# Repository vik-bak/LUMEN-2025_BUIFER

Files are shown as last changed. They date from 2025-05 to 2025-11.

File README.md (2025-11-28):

# LUMEN-2025_BUIFER
Development of the hardware and software for smart protection helmet used by construction workers. Three PCBs were design in order to expand the functionalities of the regular protection helmet, code-named after their location on the helmet: BackPCB, FrontPCB and SidePCB. Code written in C, built and loaded into the STM32L476 and ESP Wrover microcontrollers. Implemented local web application developed in React to visualize data from sensors and to notify user about important informations on the construction site. The whole system was tested and proved functional and efficient.

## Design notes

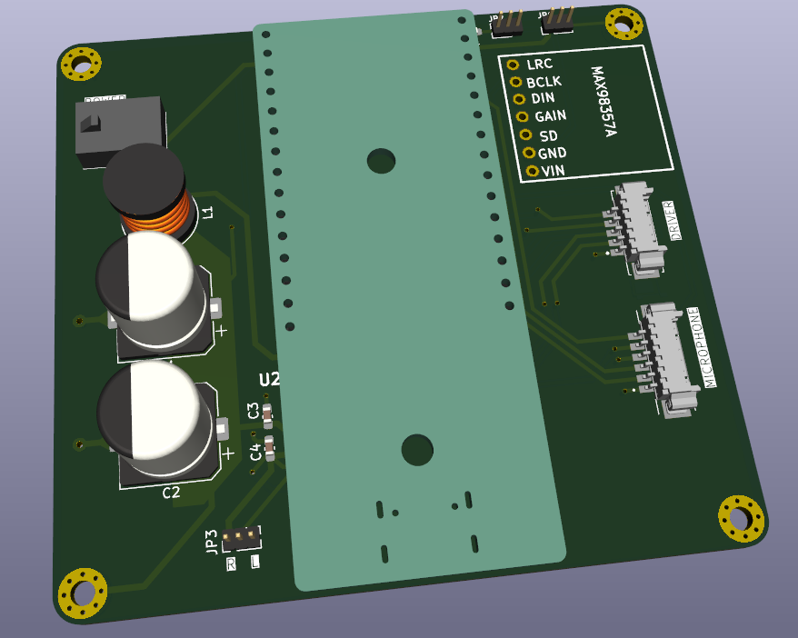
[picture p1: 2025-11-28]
Side_PCB_BUIFER/pcb_side_front.png

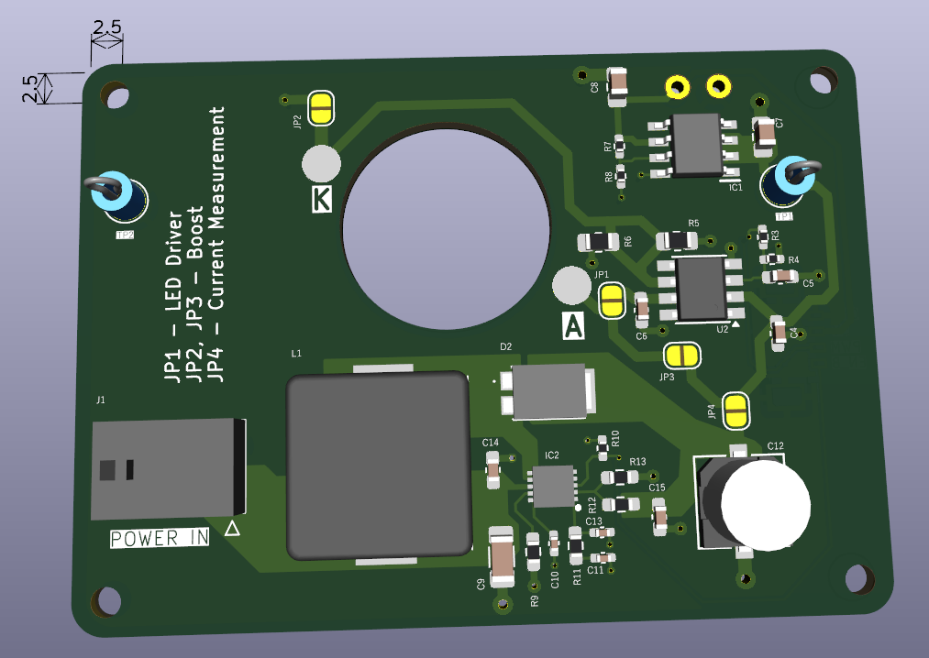
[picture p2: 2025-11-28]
Front_PCB_BUIFER/pcb_front_front.png

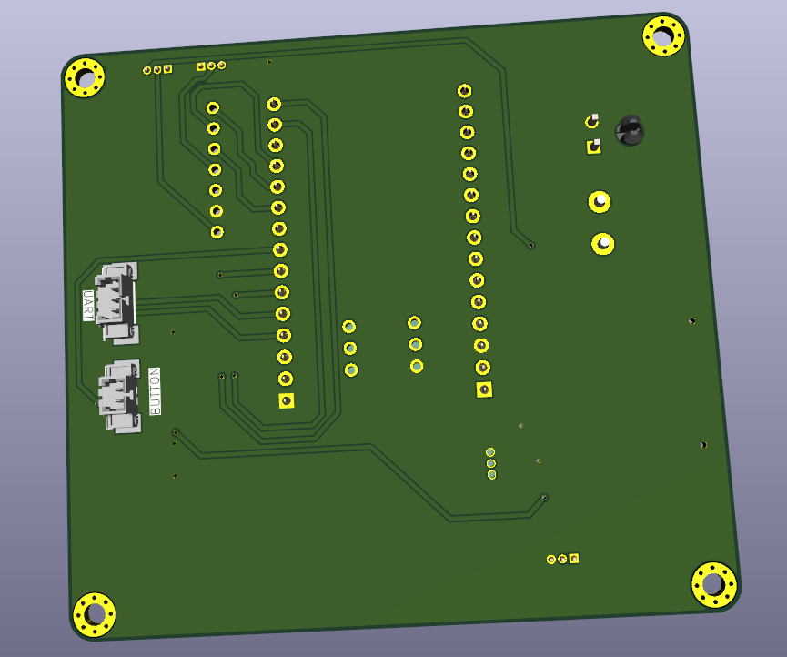
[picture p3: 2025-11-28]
Side_PCB_BUIFER/pcb_side_back.png

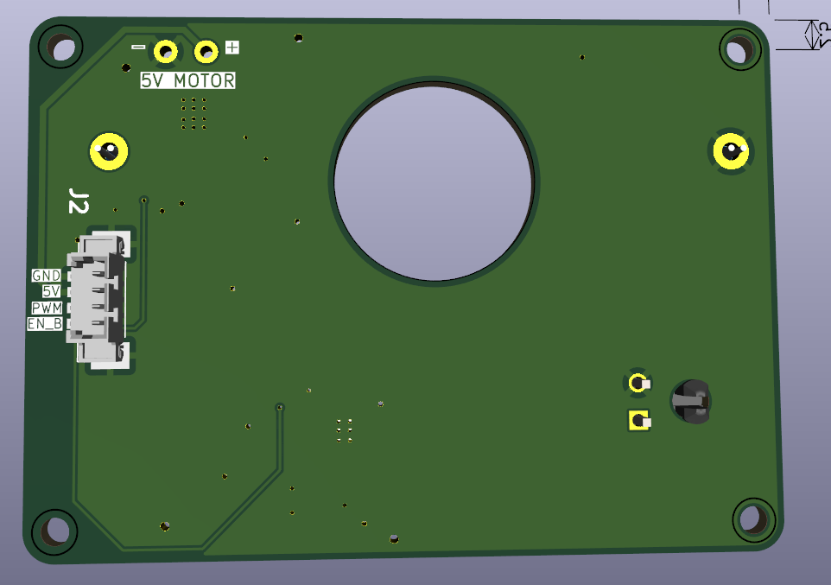
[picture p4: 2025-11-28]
Front_PCB_BUIFER/pcb_front_back.png

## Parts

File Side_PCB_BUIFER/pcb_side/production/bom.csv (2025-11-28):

Designator | Footprint | Quantity | Value | LCSC Part #
C1, C2 | CP_Elec_10x12.5 | 2 | 1000u
C3, C4 | 0603 | 2 | 1u
H1, H2, H3, H4 | MountingHole_2.5mm_Pad_Via | 4 | MountingHole_Pad
J1 | power_in | 1 | power_in
J2 | 3_pin_molex | 1 | 3-pin_molex
J3 | 2_pin_molex | 1 | 2_pin_molex
J4 | 5_pin_molex | 1 | 5_pin_molex
JP1, JP2, JP3 | PinHeader_1x03_P1.27mm_Vertical | 3 | Jumper_3_Open
K4, K5 | PinSocket_1x15_P2.54mm_Vertical | 2 | HEADER_MALE_15X1
L1 | L_Radial_D8.7mm_P5.00mm_Fastron_07HCP | 1 | 10m
R1 | 0603 | 1 | 100k
U2 | 3v3_ldo | 1 | MCP1700-3302E/TO
U3 | 6_pin_molex | 1 | INMP441
U4 | INMP441 | 1 | INMP441
U5 | MAX98357A ADAFRUIT | 1 | MAX98357 Adafruit Breakout

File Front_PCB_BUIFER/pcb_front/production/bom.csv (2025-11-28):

Designator | Footprint | Quantity | Value | LCSC Part #
 |  | 1
C10 | 0402 | 1 | 10n
C11 | 0402 | 1 | 22n
C12 | CAP_RPS&slash_PA_6P3X5P7_NCH | 1 | 39u
C13 | 0402 | 1 | 10p
C14 | 0603 | 1 | 1u
C15 | 0603 | 1 | 10u
C4, C6 | 0603 | 2 | 4u7
C5 | 0603 | 1 | 100p
C7 | 0805 | 1 | 4u7
C8 | 0805 | 1 | 10u
C9 | 1206 | 1 | 22u
D1 | LED_Cree-XHP50_6V | 1 | LED_Cree_XHP50_6V
D2 | Schottky_Diode | 1 | PDS540-13
IC1 | LDO_5V | 1 | TPS7A7001DDA
IC2 | Boost_Converter_AD | 1 | ADP1614ACPZ-1.3-R7
J1 | 215760-YY02 | 1 | 215760-3002
J2 | 4_pin_molex | 1 | 4pin_molex
L1 | WE-HCI_1350_136523 | 1 | 4u7
R10, R4 | 0402 | 2 | 10k
R11 | 0603 | 1 | 4.22k
R12 | 0603 | 1 | 191k
R13 | 0603 | 1 | 50k
R3 | 0402 | 1 | 10R
R5 | 0805 | 1 | 0.1R
R6 | 0805 | 1 | 0.15R
R7 | 0402 | 1 | 274k
R8 | 0402 | 1 | 30.1k
R9 | 0603 | 1 | 59k
TP1, TP2 | TestPoint_Loop_D2.54mm_Drill1.5mm_Beaded | 2 | TestPoint
U2 | Diodes_SO-8EP | 1 | LED_DRIVER_PAM

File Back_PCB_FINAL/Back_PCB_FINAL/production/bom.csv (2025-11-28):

Designator | Footprint | Quantity | Value | LCSC Part #
C10, C11, C13, C3, C4, C5, C6, C7, C8, C9 | 0603 | 10 | 100n
C12 | 0603 | 1 | 10n
C2, CIN1, COUT1 | 0603 | 3 | 10u
H1, H2, H3, H4 | MountingHole_3.2mm_M3 | 4 | MountingHole
IC1 | SOIC127P600X170-9N | 1 | TPS7A7001DDA
J1 | 215760-YY02 | 1 | 215760-3002
J10 | MEM20610118800A | 1 | MEM2061-01-188-00-A
J11, J12, J13 | 533980276 | 3 | 53398-0276
J2, J9 | 53398-0371 | 2 | 53398-0376
J3 | 533980671 | 1 | 53398-0671
J4, J6, J7, J8 | 533980471 | 4 | 53398-0471
J5 | 53398-0571 | 1 | 53398-0571
K1, K2 | PinSocket_1x15_P2.54mm_Vertical | 2 | HEADER_MALE_15X1
N1, N2 | Connector_PinSocket_2.54mm_NUCLEO | 2 | Conn_02x19_Odd_Even
R1 | 0603 | 1 | 169k
R10 | 0603 | 1 | 3.74k
R11, R2, R7, R9 | 0603 | 4 | 30.1k
R3 | 0603 | 1 | 10k
R4, R5 | 0603 | 2 | 1k
R6, R8 | 0603 | 2 | 15.4k
TP1, TP2 | PinHeader_1x01_P2.54mm_Vertical | 2 | TestPoint
VR1 | TS7Y103KR32 | 1 | TS7Y103KR32

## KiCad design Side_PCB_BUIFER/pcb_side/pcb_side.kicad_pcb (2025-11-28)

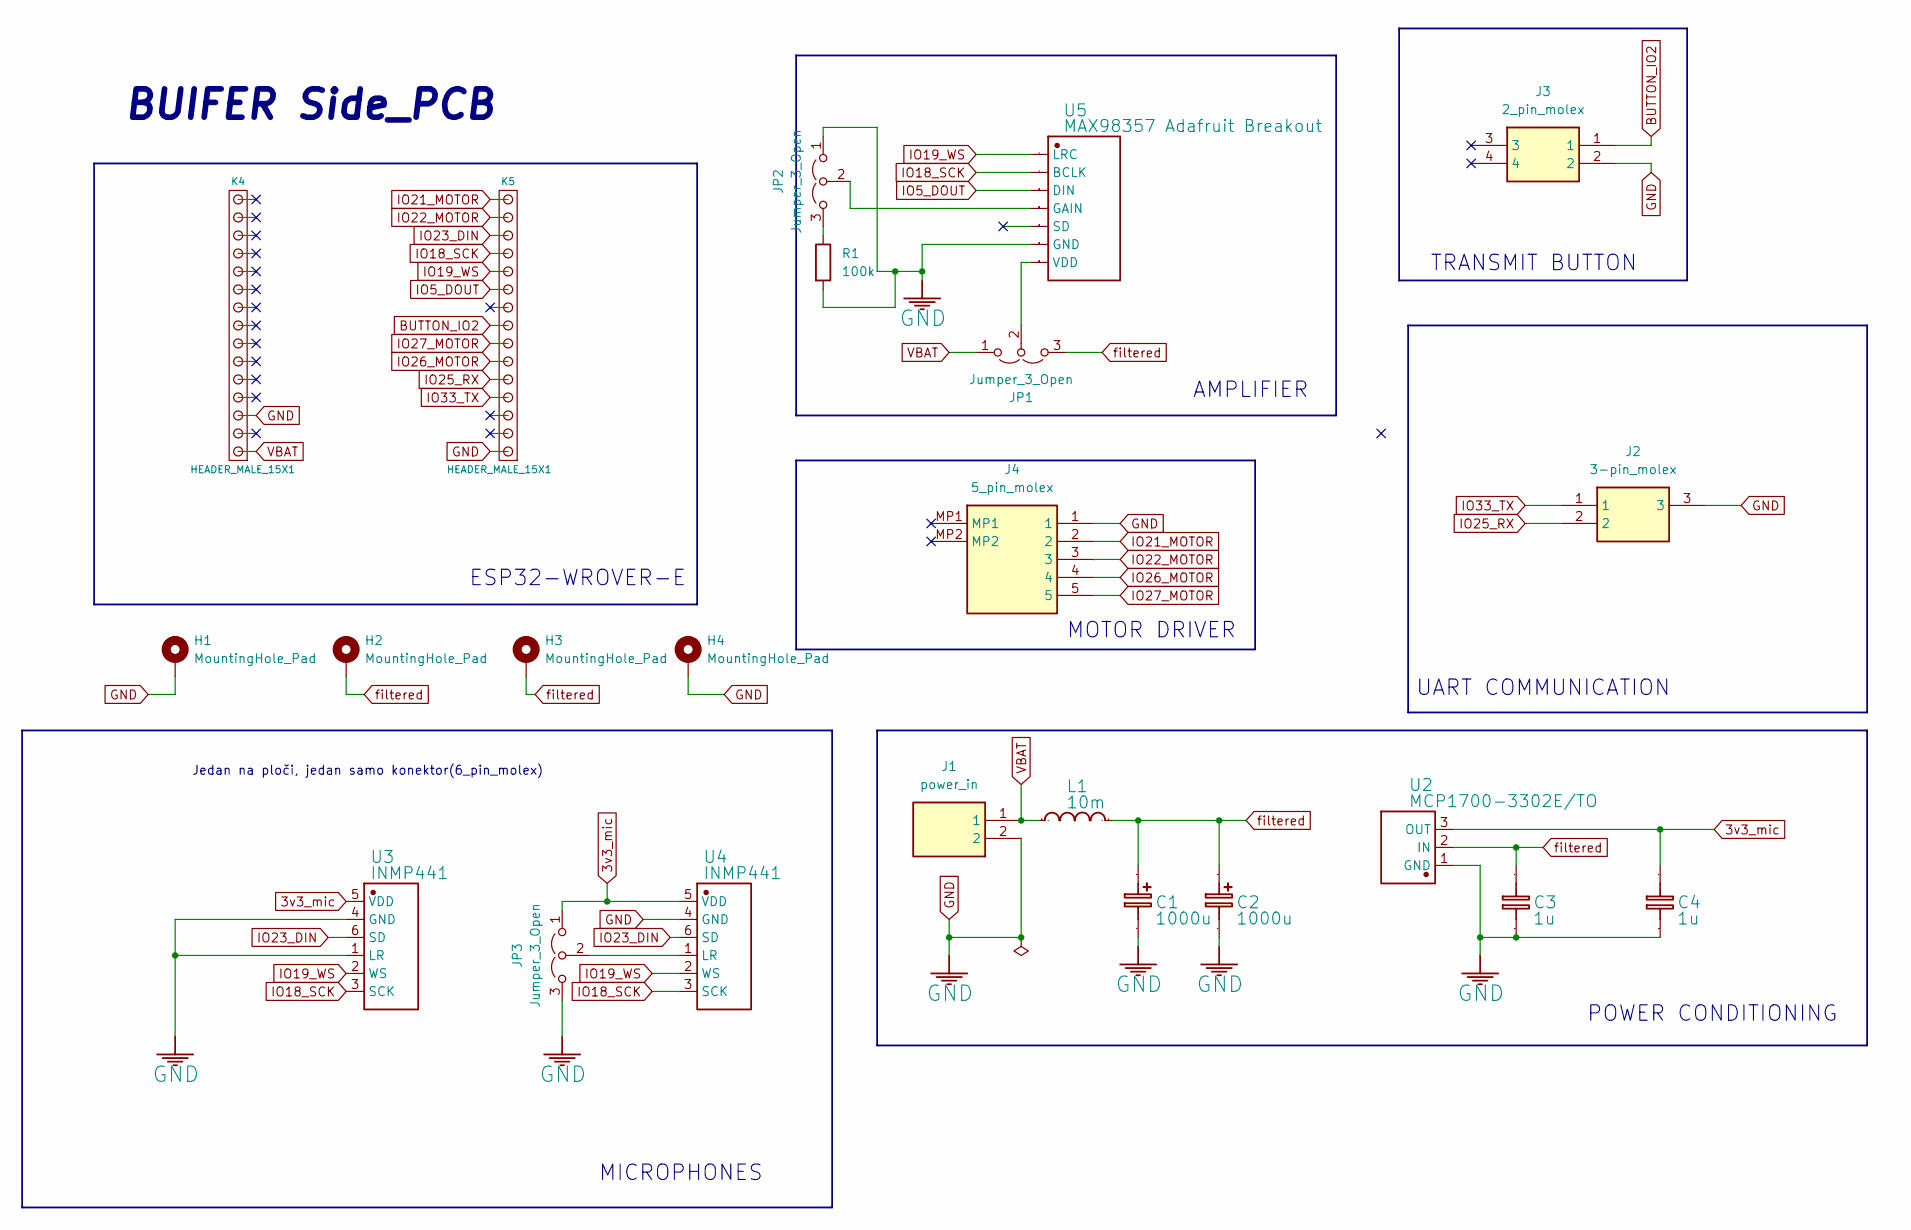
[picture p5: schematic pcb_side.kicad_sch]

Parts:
C1, C2: 1000u; CP_Elec_10x12.5
C3, C4: 1u; C_0603_1608Metric_Pad1.08x0.95mm_HandSolder
H1, H2, H3, H4: MountingHole_Pad; MountingHole_2.5mm_Pad_Via
J1: power_in; Mouser Part Number 538-215760-3002
J2: 3-pin_molex; 3_pin_molex; Mouser Part Number 538-53398-0376
J3: 2_pin_molex; Mouser Part Number 538-53398-0276
J4: 5_pin_molex; Mouser Part Number 538-53261-0571
JP1, JP2, JP3: Jumper_3_Open; PinHeader_1x03_P1.27mm_Vertical
K4, K5: HEADER_MALE_15X1; PinSocket_1x15_P2.54mm_Vertical
L1: 10m; L_Radial_D8.7mm_P5.00mm_Fastron_07HCP
R1: 100k; R_0603_1608Metric_Pad0.98x0.95mm_HandSolder
U2: MCP1700-3302E/TO; 3v3_ldo; Manufacturer Part MCP1700-3302E/TO
U3: INMP441; 6_pin_molex
U4: INMP441
U5: MAX98357 Adafruit Breakout; MAX98357A ADAFRUIT

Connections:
3v3_mic: C4.2, JP3.1 (A), U2.3 (OUT), U3.5 (VDD), U4.5 (VDD)
BUTTON_IO2: J3.1, K5.8
GND: C1.2, C2.2, C3.1, C4.1, H1.1, H4.1, J1.2, J2.3, J3.2, J4.1, JP2.1 (A), JP3.3 (B), K4.3, K5.1, R1.2, U2.1 (GND), U3.1 (LR), U3.4 (GND), U4.4 (GND), U5.13 (GND)
IO5_DOUT: K5.10, U5.10 (DIN)
IO18_SCK: K5.12, U3.3 (SCK), U4.3 (SCK), U5.9 (BCLK)
IO19_WS: K5.11, U3.2 (WS), U4.2 (WS), U5.8 (LRC)
IO21_MOTOR: J4.2, K5.15
IO22_MOTOR: J4.3, K5.14
IO23_DIN: K5.13, U3.6 (SD), U4.6 (SD)
IO25_RX: J2.2, K5.5
IO26_MOTOR: J4.4, K5.6
IO27_MOTOR: J4.5, K5.7
IO33_TX: J2.1, K5.4
unnamed: JP1.2 (C), U5.14 (VDD)
unnamed: JP2.3 (B), R1.1
unnamed: JP2.2 (C), U5.11 (GAIN)
unnamed: JP3.2 (C), U4.1 (LR)
VBAT: J1.1, JP1.1 (A), K4.1, L1.1
filtered: C1.1, C2.1, C3.2, H2.1, H3.1, JP1.3 (B), L1.2, U2.2 (IN)

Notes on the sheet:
AMPLIFIER
TRANSMIT BUTTON
Jedan na ploči, jedan samo konektor(6_pin_molex)
ESP32-WROVER-E
BUIFER Side_PCB
MOTOR DRIVER
UART COMMUNICATION
POWER CONDITIONING
MICROPHONES

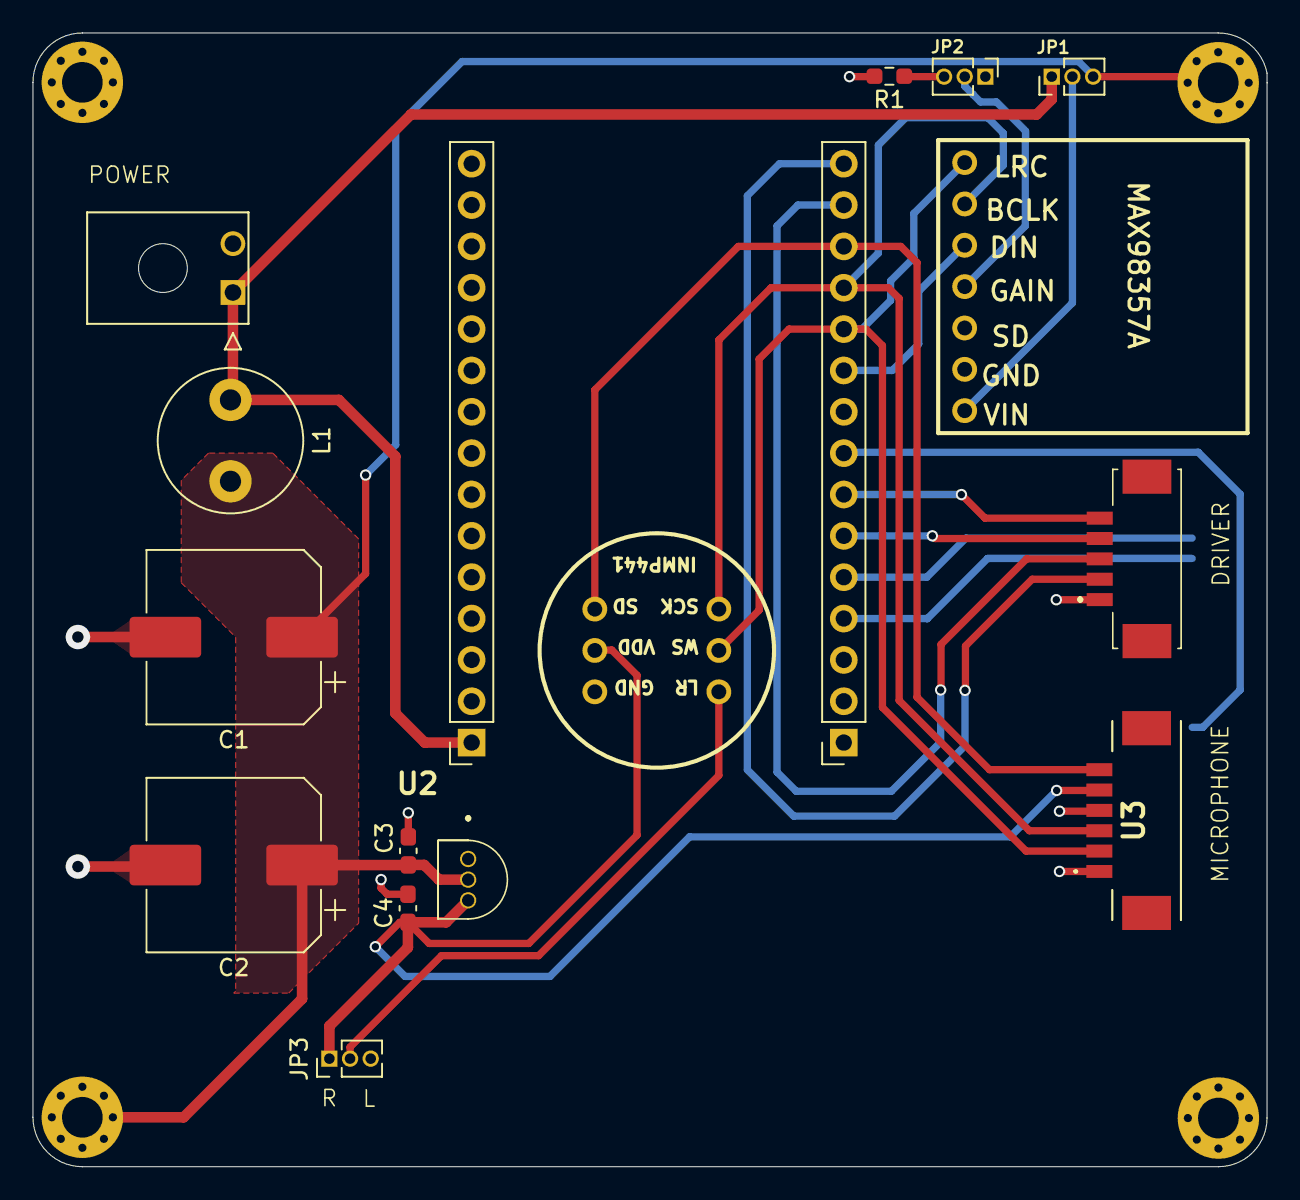
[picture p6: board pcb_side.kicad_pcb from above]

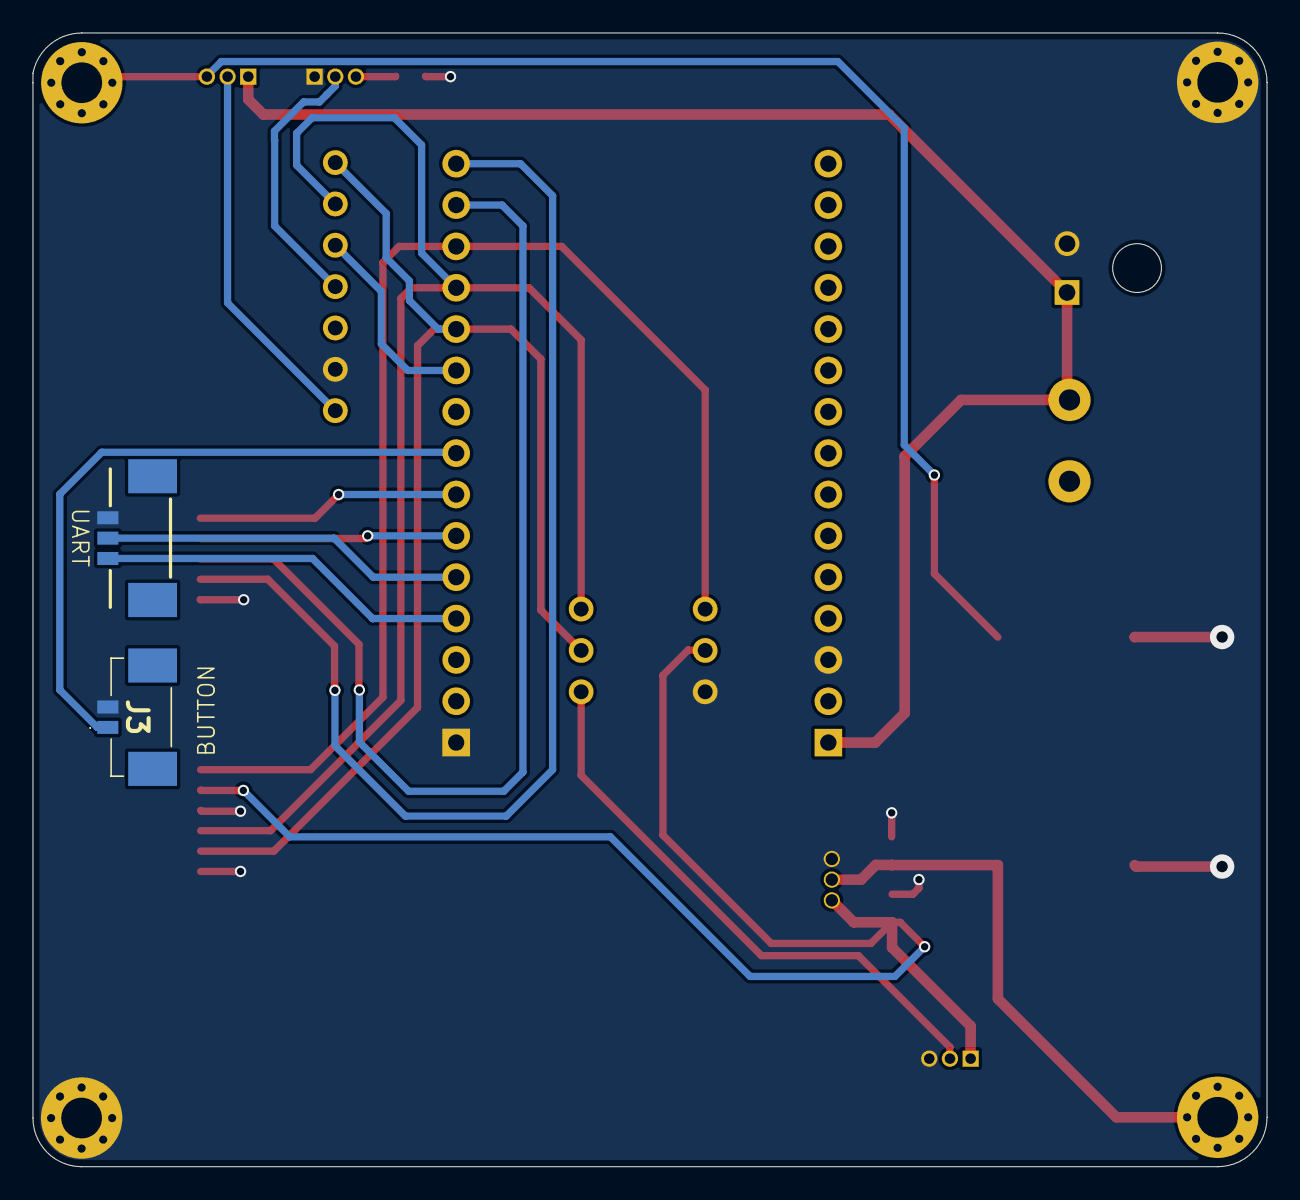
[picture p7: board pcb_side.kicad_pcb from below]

Board: 2 copper layers, 75.8 x 69.6 mm, 23 parts (2 on the bottom side), 19 nets.

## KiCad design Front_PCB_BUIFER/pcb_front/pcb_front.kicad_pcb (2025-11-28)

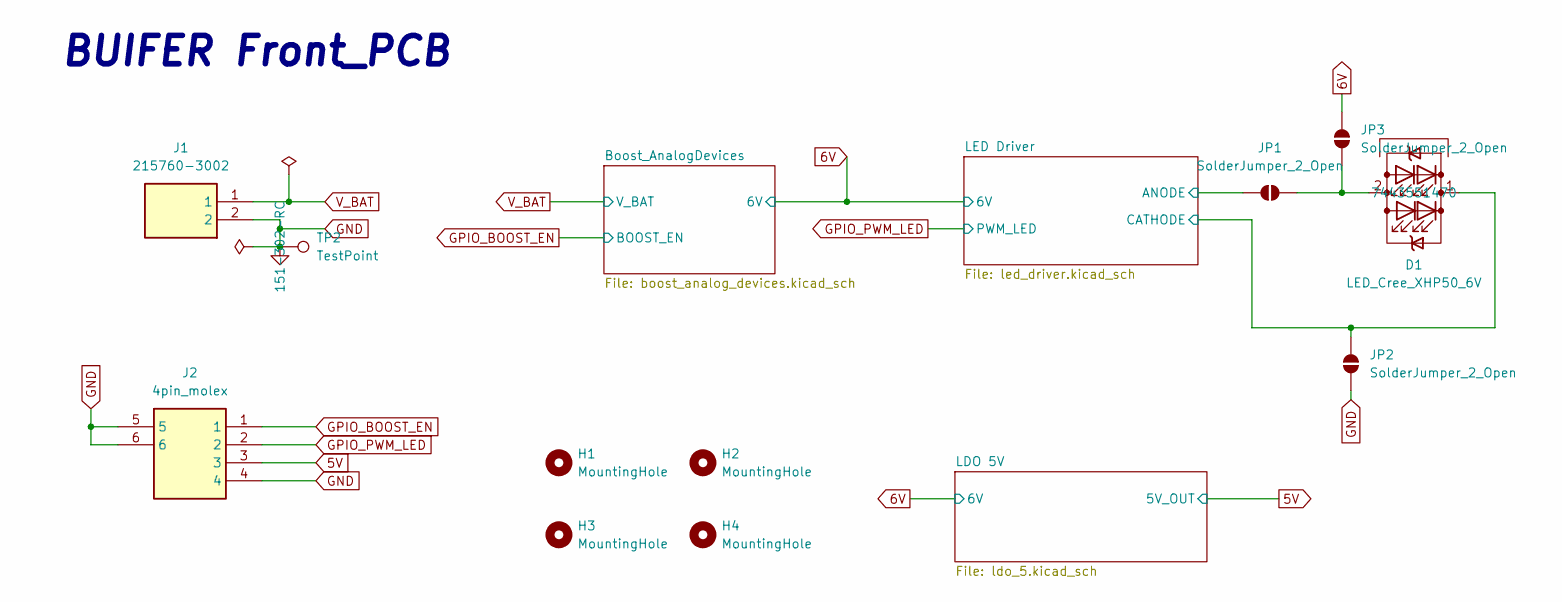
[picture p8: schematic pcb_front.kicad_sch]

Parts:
D1: LED_Cree_XHP50_6V; LED_Cree-XHP50_6V; Manufacturer_Part_Number 7443551470
H1, H2, H3, H4: MountingHole; MountingHole_2.2mm_M2_ISO7380
J1: 215760-3002; 215760-YY02; Mouser Part Number 538-215760-3002
J2: 4pin_molex; 4_pin_molex; Mouser Part Number 538-53398-0471
JP1, JP2, JP3: SolderJumper_2_Open; SolderJumper-2_P1.3mm_Open_RoundedPad1.0x1.5mm
TP2: TestPoint; TestPoint_Loop_D2.54mm_Drill1.5mm_Beaded; Manufacturer_Part_Number 151-302-RC

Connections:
5V: J2.3; also elsewhere on the board
6V: JP3.2 (B); also elsewhere on the board
/LED Driver/ANODE: JP1.1 (A); also elsewhere on the board
/LED Driver/CATHODE: D1.1 (K), JP2.2 (B); also elsewhere on the board
GND: J1.2, J2.4, J2.5, J2.6, JP2.1 (A), TP2.1; also elsewhere on the board
GPIO_BOOST_EN: J2.1; also elsewhere on the board
GPIO_PWM_LED: J2.2; also elsewhere on the board
unnamed: D1.2 (A), JP1.2 (B), JP3.1 (A)
V_BAT: J1.1; also elsewhere on the board

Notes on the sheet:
BUIFER Front_PCB

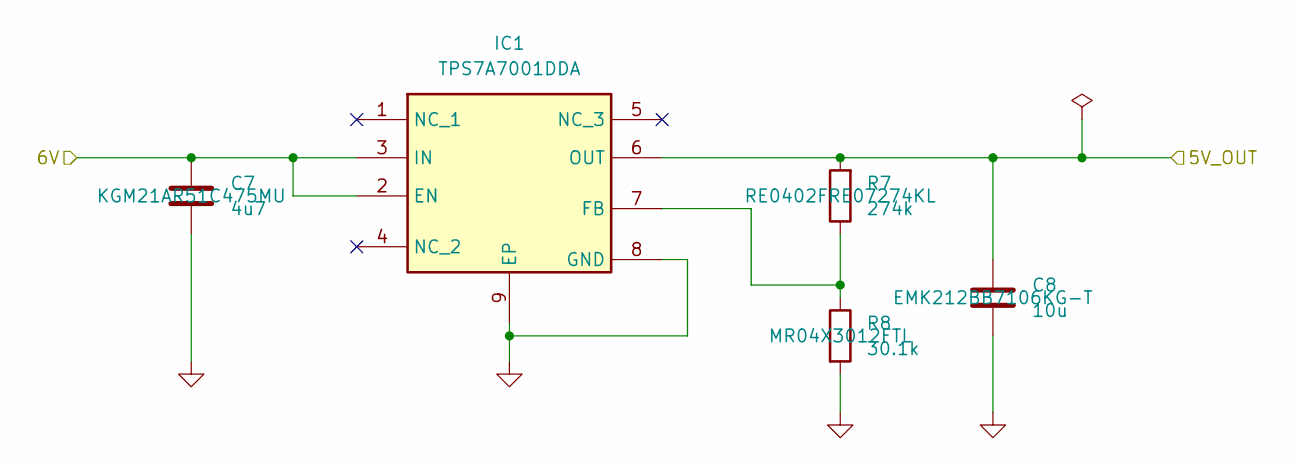
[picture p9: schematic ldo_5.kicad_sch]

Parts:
C7: 4u7; C_0805_2012Metric_Pad1.18x1.45mm_HandSolder; Manufacturer_Part_Number KGM21AR51C475MU
C8: 10u; C_0805_2012Metric_Pad1.18x1.45mm_HandSolder; Manufacturer_Part_Number EMK212BB7106KG-T
IC1: TPS7A7001DDA; LDO_5V; Mouser Part Number 595-TPS7A7001DDA
R7: 274k; R_0402_1005Metric_Pad0.72x0.64mm_HandSolder; Manufacturer_Part_Number RE0402FRE07274KL
R8: 30.1k; R_0402_1005Metric_Pad0.72x0.64mm_HandSolder; Manufacturer_Part_Number MR04X3012FTL

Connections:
5V: C8.1, IC1.6 (OUT), R7.2; also elsewhere on the board
6V: C7.1, IC1.2 (EN), IC1.3 (IN); also elsewhere on the board
GND: C7.2, C8.2, IC1.8 (GND), IC1.9 (EP), R8.2; also elsewhere on the board
unnamed: IC1.7 (FB), R7.1, R8.1

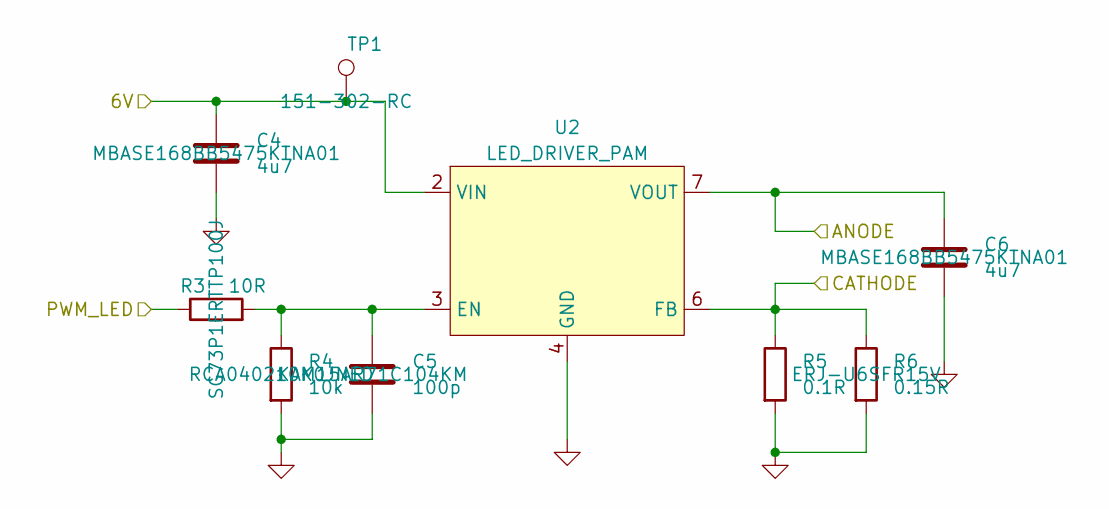
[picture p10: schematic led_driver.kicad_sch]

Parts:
C4, C6: 4u7; C_0603_1608Metric_Pad1.08x0.95mm_HandSolder; Manufacturer_Part_Number MBASE168BB5475KTNA01
C5: 100p; C_0603_1608Metric_Pad1.08x0.95mm_HandSolder; Manufacturer_Part_Number KAM15AR71C104KM
R3: 10R; R_0402_1005Metric_Pad0.72x0.64mm_HandSolder; Manufacturer_Part_Number SG73P1ERTTP100J
R4: 10k; R_0402_1005Metric_Pad0.72x0.64mm_HandSolder; Manufacturer_Part_Number RCA040210K0JNED
R5: 0.1R; R_0805_2012Metric_Pad1.20x1.40mm_HandSolder; Manufacturer_Part_Number ERJ-U6SFR10V
R6: 0.15R; R_0805_2012Metric_Pad1.20x1.40mm_HandSolder; Manufacturer_Part_Number ERJ-U6SFR15V
TP1: TestPoint; TestPoint_Loop_D2.54mm_Drill1.5mm_Beaded; Manufacturer_Part_Number 151-302-RC
U2: LED_DRIVER_PAM; Diodes_SO-8EP

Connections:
6V: C4.1, TP1.1, U2.2 (VIN); also elsewhere on the board
/LED Driver/ANODE: C6.1, U2.7 (VOUT); also elsewhere on the board
/LED Driver/CATHODE: R5.1, R6.1, U2.6 (FB); also elsewhere on the board
GND: C4.2, C5.2, C6.2, R4.2, R5.2, R6.2, U2.4 (GND); also elsewhere on the board
GPIO_PWM_LED: R3.1; also elsewhere on the board
unnamed: C5.1, R3.2, R4.1, U2.3 (EN)

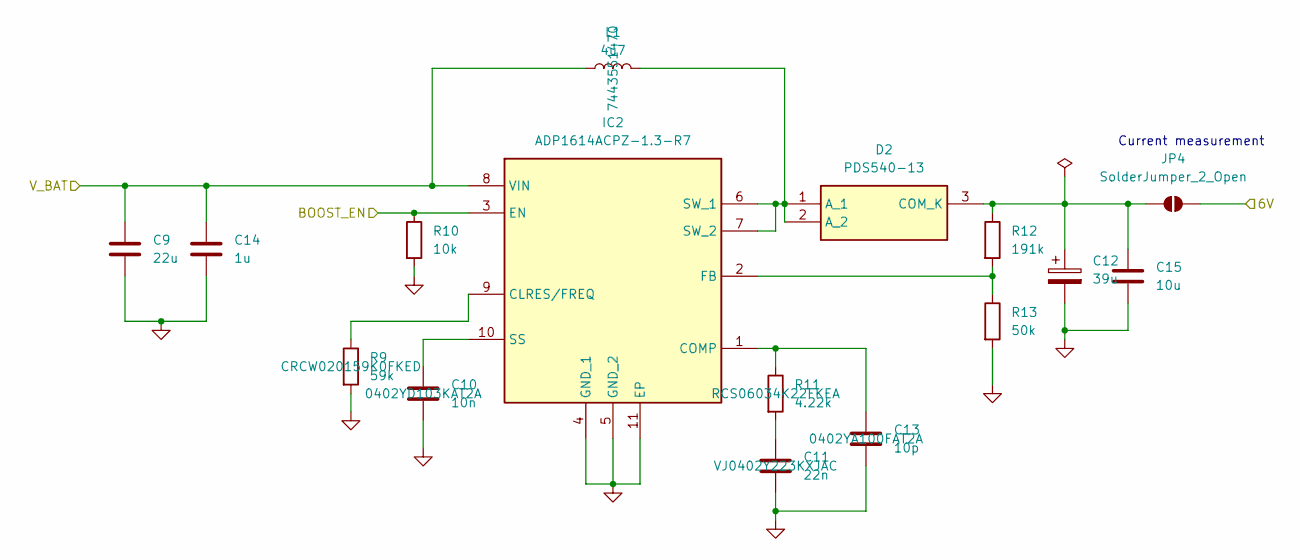
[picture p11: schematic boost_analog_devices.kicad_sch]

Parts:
C9: 22u; C_1206_3216Metric_Pad1.33x1.80mm_HandSolder; Manufacturer_Part_Number EMK316BJ226ML-T
C10: 10n; C_0402_1005Metric_Pad0.74x0.62mm_HandSolder; Manufacturer_Part_Number 0402YD103KAT2A
C11: 22n; C_0402_1005Metric_Pad0.74x0.62mm_HandSolder; Manufacturer_Part_Number VJ0402Y223KXJAC
C12: 39u; CAP_RPS&slash_PA_6P3X5P7_NCH; Manufacturer_Part_Number RPA1C390MCN1GS
C13: 10p; C_0402_1005Metric_Pad0.74x0.62mm_HandSolder; Manufacturer_Part_Number 0402YA100FAT2A
C14: 1u; C_0603_1608Metric_Pad1.08x0.95mm_HandSolder; Manufacturer_Part_Number GRM188R61A105KA61D
C15: 10u; C_0603_1608Metric_Pad1.08x0.95mm_HandSolder; Manufacturer_Part_Number KGM15CR51C106KT
D2: PDS540-13; Schottky_Diode; Mouser Part Number 621-PDS540-13
IC2: ADP1614ACPZ-1.3-R7; Boost_Converter_AD; Mouser Part Number 584-ADP1614ACPZ1.3R7
JP4: SolderJumper_2_Open; SolderJumper-2_P1.3mm_Open_RoundedPad1.0x1.5mm
L1: 4u7; WE-HCI_1350_136523; Manufacturer_Part_Number 7443551470
R9: 59k; R_0603_1608Metric_Pad0.98x0.95mm_HandSolder; Manufacturer_Part_Number CRCW020159K0FKED
R10: 10k; R_0402_1005Metric_Pad0.72x0.64mm_HandSolder; Manufacturer_Part_Number RCA040210K0JNED
R11: 4.22k; R_0603_1608Metric_Pad0.98x0.95mm_HandSolder; Manufacturer_Part_Number RCS06034K22FKEA
R12: 191k; R_0603_1608Metric_Pad0.98x0.95mm_HandSolder; Manufacturer_Part_Number RR0816P-1913-D-28D
R13: 50k; R_0603_1608Metric_Pad0.98x0.95mm_HandSolder; Manufacturer_Part_Number RT0603BRD0750KL

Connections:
6V: JP4.2 (B); also elsewhere on the board
GND: C9.2, C10.2, C11.2, C12.2, C13.2, C14.2, C15.2, IC2.4 (GND_1), IC2.5 (GND_2), IC2.11 (EP), R9.2, R10.2, R13.2; also elsewhere on the board
GPIO_BOOST_EN: IC2.3 (EN), R10.1; also elsewhere on the board
unnamed: C11.1, R11.2
unnamed: D2.1 (A_1), D2.2 (A_2), IC2.6 (SW_1), IC2.7 (SW_2), L1.2
unnamed: C12.1, C15.1, D2.3 (COM_K), JP4.1 (A), R12.1
unnamed: IC2.9 (CLRES/FREQ), R9.1
unnamed: C13.1, IC2.1 (COMP), R11.1
unnamed: IC2.2 (FB), R12.2, R13.1
unnamed: C10.1, IC2.10 (SS)
V_BAT: C9.1, C14.1, IC2.8 (VIN), L1.1; also elsewhere on the board

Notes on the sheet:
Current measurement

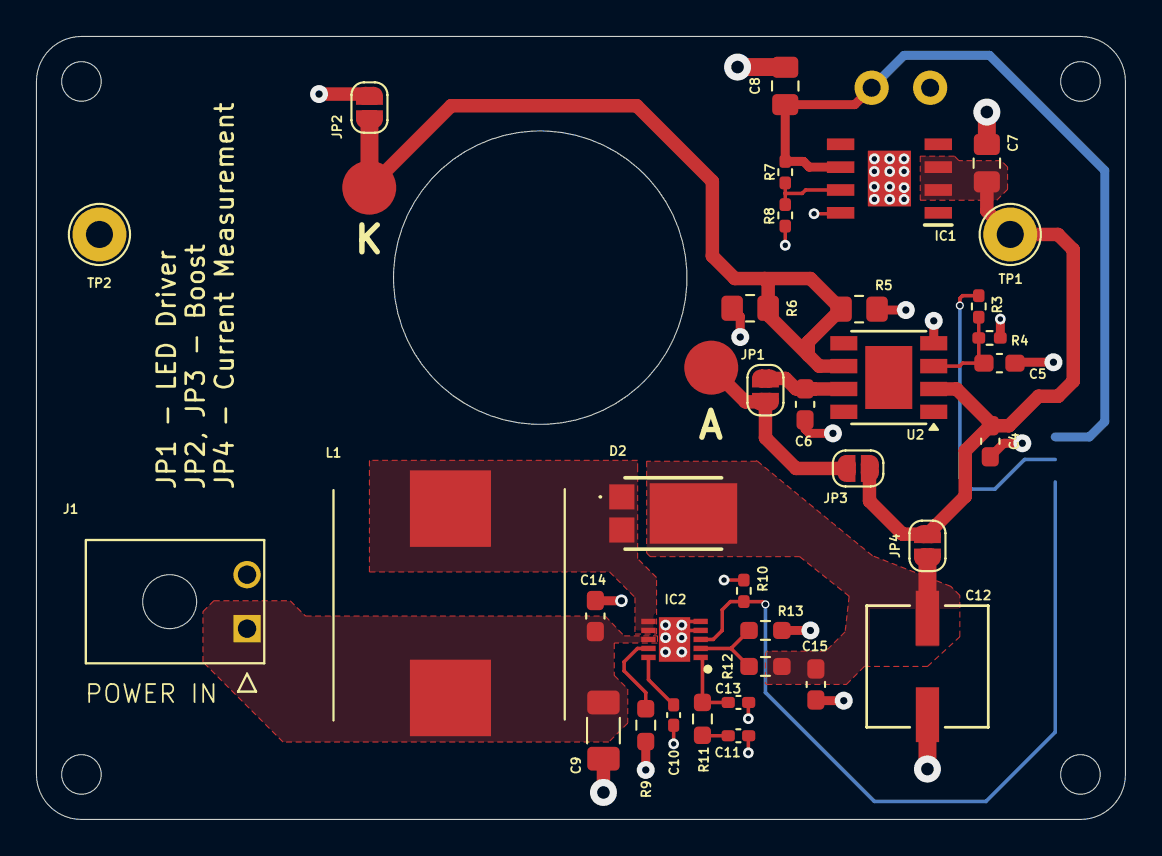
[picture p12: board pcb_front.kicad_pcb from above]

Board: 2 copper layers, 60.5 x 43.5 mm, 41 parts (1 on the bottom side), 18 nets.

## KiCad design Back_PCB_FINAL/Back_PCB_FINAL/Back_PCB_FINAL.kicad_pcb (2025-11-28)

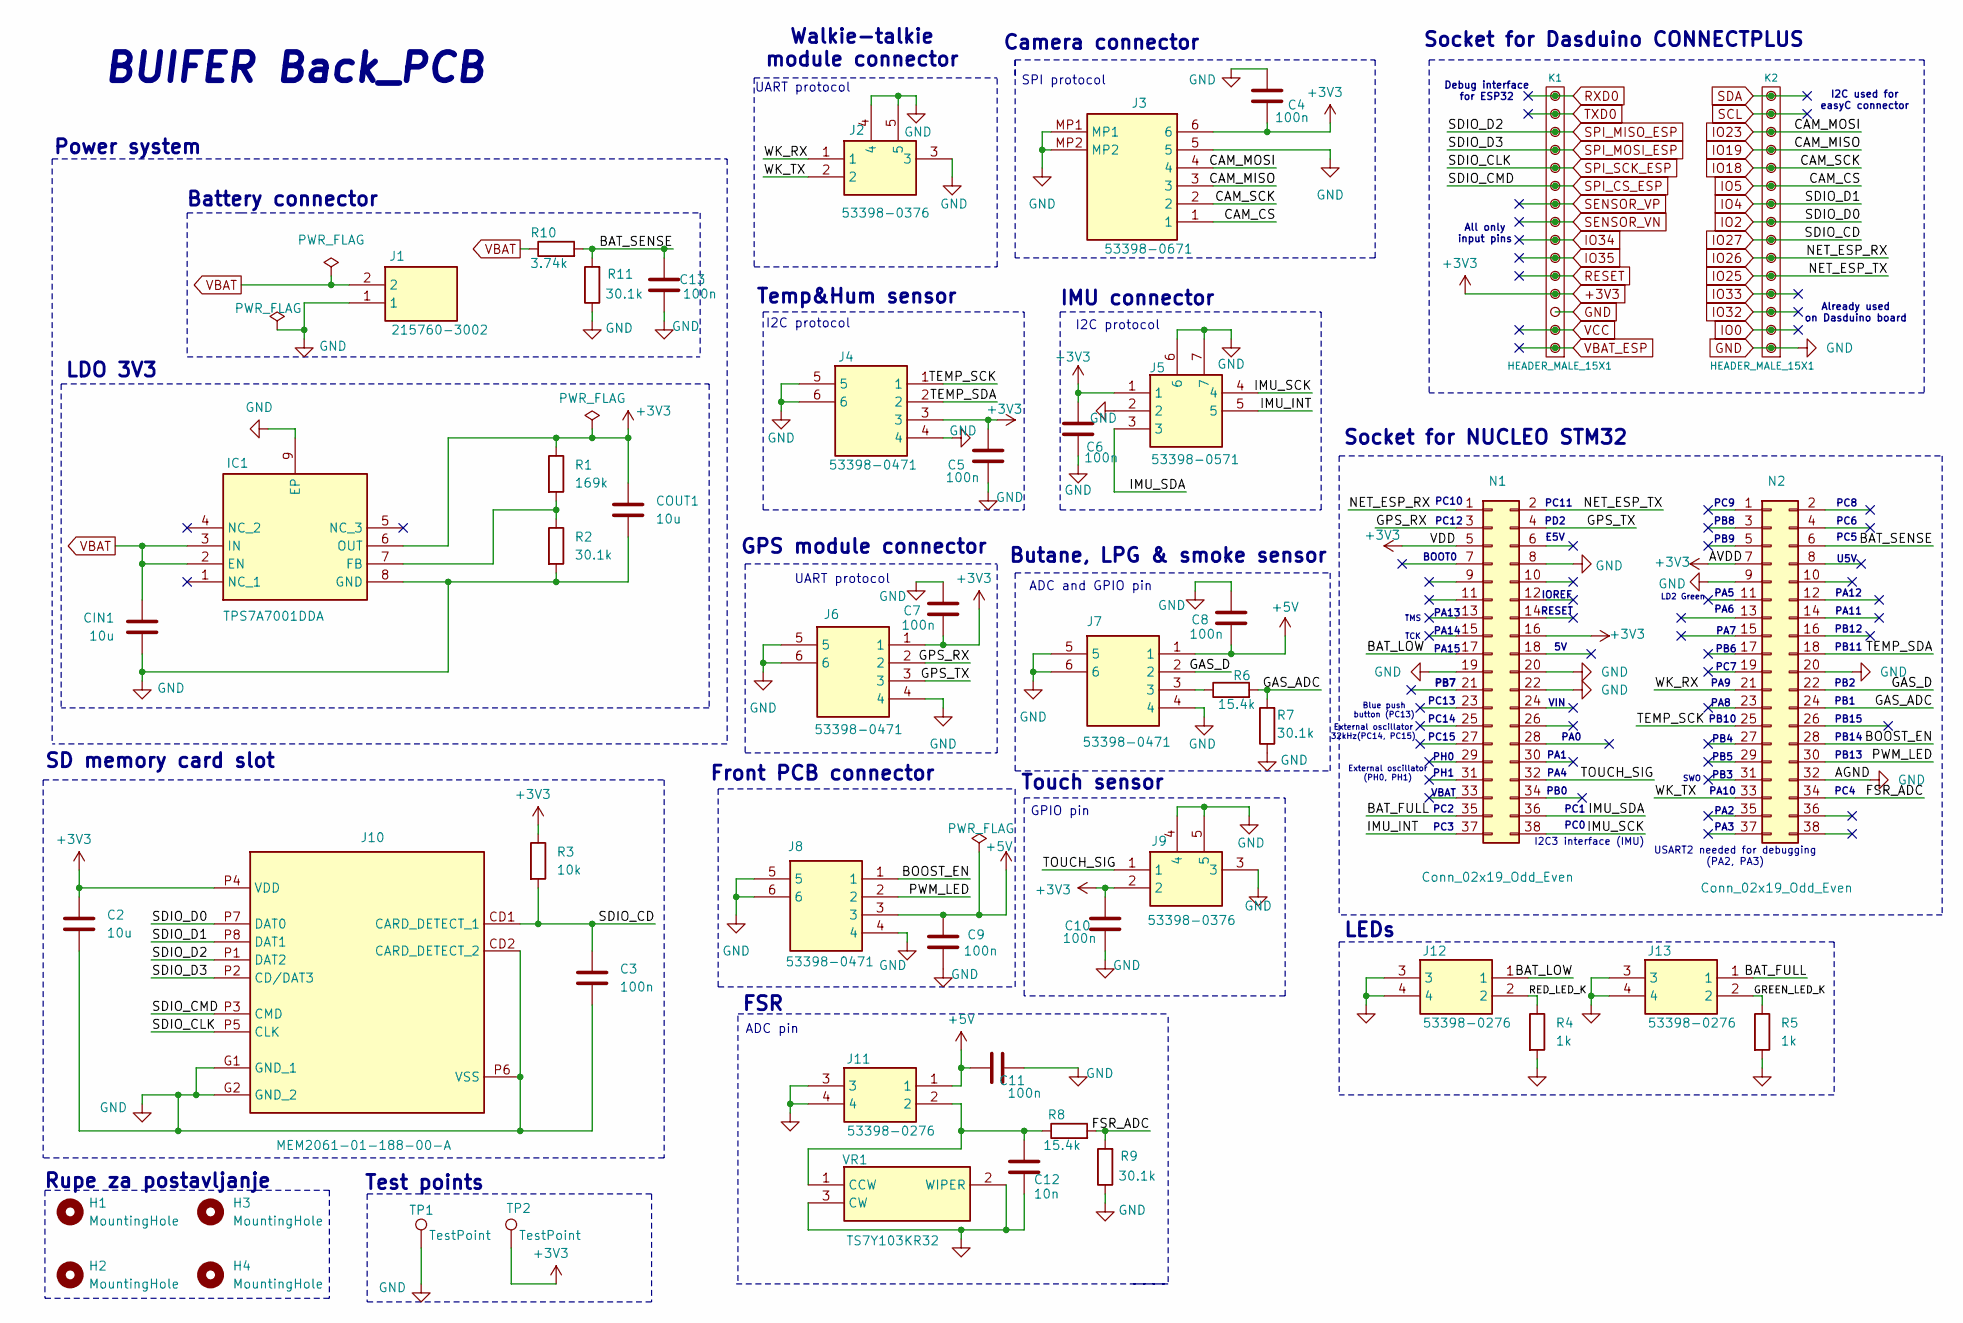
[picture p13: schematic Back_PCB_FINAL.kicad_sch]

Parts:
C2: 10u; C_0603_1608Metric_Pad1.08x0.95mm_HandSolder
C3, C4, C5, C6, C7, C8, C9, C10, C11, C13: 100n; C_0603_1608Metric_Pad1.08x0.95mm_HandSolder
C12: 10n; C_0603_1608Metric_Pad1.08x0.95mm_HandSolder
CIN1: 10u; C_0603_1608Metric_Pad1.08x0.95mm_HandSolder
COUT1: 10u; C_0603_1608Metric_Pad1.08x0.95mm_HandSolder
H1, H2, H3, H4: MountingHole; MountingHole_3.2mm_M3
IC1: TPS7A7001DDA; SOIC127P600X170-9N; Mouser Part Number 595-TPS7A7001DDA
J1: 215760-3002; 215760-YY02; Mouser Part Number 538-215760-3002
J2, J9: 53398-0376; 53398-0371; Mouser Part Number 538-53398-0376
J3: 53398-0671; 533980671; Mouser Part Number 538-53398-0671
J4, J6, J7, J8: 53398-0471; 533980471; Mouser Part Number 538-53398-0471
J5: 53398-0571; Mouser Part Number 538-53398-0571
J10: MEM2061-01-188-00-A; MEM20610118800A; Mouser Part Number 640-MEM20610118800A
J11, J12, J13: 53398-0276; 533980276; Mouser Part Number 538-53398-0276
K1, K2: HEADER_MALE_15X1; PinSocket_1x15_P2.54mm_Vertical
N1, N2: Conn_02x19_Odd_Even; Connector_PinSocket_2.54mm_NUCLEO
R1: 169k; R_0603_1608Metric_Pad0.98x0.95mm_HandSolder
R2, R7, R9, R11: 30.1k; R_0603_1608Metric_Pad0.98x0.95mm_HandSolder
R3: 10k; R_0603_1608Metric_Pad0.98x0.95mm_HandSolder
R4, R5: 1k; R_0603_1608Metric_Pad0.98x0.95mm_HandSolder
R6, R8: 15.4k; R_0603_1608Metric_Pad0.98x0.95mm_HandSolder
R10: 3.74k; R_0603_1608Metric_Pad0.98x0.95mm_HandSolder
TP1, TP2: TestPoint; PinHeader_1x01_P2.54mm_Vertical
VR1: TS7Y103KR32; Mouser Part Number 72-TS7Y103KR32

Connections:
+3V3: C2.1, C4.1, C5.1, C6.1, C7.1, C10.1, COUT1.2, IC1.6 (OUT), J3.6, J4.3, J5.1, J6.1, J9.2, J10.P4 (VDD), K1.4, N1.5, N1.16, N2.7, R1.1, R3.1, TP2.1
+5V: C8.1, C9.1, C11.1, J7.1, J8.3, J11.1
/BAT_FULL: J13.1, N1.35
/BAT_LOW: J12.1, N1.17
/BAT_SENSE: C13.1, N2.6, R10.2, R11.2
/BOOST_EN: J8.1, N2.28
/FSR_ADC: N2.34, R8.2, R9.2
/GAS_ADC: N2.24, R6.2, R7.2
/GAS_D: J7.2, N2.22
/GPS_RX: J6.2, N1.3
/GPS_TX: J6.3, N1.4
/GREEN_LED_K: J13.2, R5.1
/IMU_INT: J5.5, N1.37
/IMU_SCK: J5.4, N1.38
/IMU_SDA: J5.3, N1.36
/PWM_LED: J8.2, N2.30
/RED_LED_K: J12.2, R4.1
/TEMP_SCK: J4.1, N2.25
/TEMP_SDA: J4.2, N2.18
/TOUCH_SIG: J9.1, N1.32
/WK_RX: J2.1, N2.21
/WK_TX: J2.2, N2.33
GND: C2.2, C3.2, C4.2, C5.2, C6.2, C7.2, C8.2, C9.2, C10.2, C11.2, C12.2, C13.2, CIN1.2, COUT1.1, IC1.8 (GND), IC1.9 (EP), J1.1, J2.3, J2.4, J2.5, J3.5, J3.MP1, J3.MP2, J4.4, J4.5, J4.6, J5.2, J5.6, J5.7, J6.4, J6.5, J6.6, J7.4, J7.5, J7.6, J8.4, J8.5, J8.6, J9.3, J9.4, J9.5, J10.CD2 (CARD_DETECT_2), J10.G1 (GND_1), J10.G2 (GND_2), J10.P6 (VSS), J11.3, J11.4, J12.3, J12.4, J13.3, J13.4, K1.3, K2.1, N1.8, N1.19, N1.20, N1.22, N2.9, N2.20, N2.32, R2.2, R4.2, R5.2, R7.1, R9.1, R11.1, TP1.1, VR1.2 (WIPER), VR1.3 (CW)
IO0: K2.2
IO2: J10.P7 (DAT0), K2.8
IO4: J10.P8 (DAT1), K2.9
IO5: J3.1, K2.10
IO18: J3.2, K2.11
IO19: J3.3, K2.12
IO23: J3.4, K2.13
IO25: K2.5, N1.2
IO26: K2.6, N1.1
IO27: C3.1, J10.CD1 (CARD_DETECT_1), K2.7, R3.2
IO32: K2.3
IO33: K2.4
IO34: K1.7
IO35: K1.6
unnamed: IC1.7 (FB), R1.2, R2.1
unnamed: J7.3, R6.1
unnamed: C12.1, J11.2, R8.1, VR1.1 (CCW)
RESET: K1.5
RXD0: K1.15
SCL: K2.14
SDA: K2.15
SENSOR_VN: K1.8
SENSOR_VP: K1.9
SPI_CS_ESP: J10.P3 (CMD), K1.10
SPI_MISO_ESP: J10.P1 (DAT2), K1.13
SPI_MOSI_ESP: J10.P2 (CD/DAT3), K1.12
SPI_SCK_ESP: J10.P5 (CLK), K1.11
TXD0: K1.14
VBAT: CIN1.1, IC1.2 (EN), IC1.3 (IN), J1.2, R10.1
VBAT_ESP: K1.1
VCC: K1.2

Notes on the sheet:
PC0
USART2 needed for debugging (PA2, PA3)
I2C3 interface (IMU)
PB1
BOOT0
ADC pin
PA6
IOREF
PB14
PA8
PB0
Butane, LPG & smoke sensor
PB12
PC11
PB8
Socket for Dasduino CONNECTPLUS
PH0
PB7
PC2
PD2
TCK
PA7
PC10
UART protocol
PB4
PC15
SD memory card slot
PB2
PA11
External oscillator (PH0, PH1)
SPI protocol
FSR
PC8
PA1
Blue push button (PC13)
Camera connector
PC13
PB15
I2C protocol
E5V

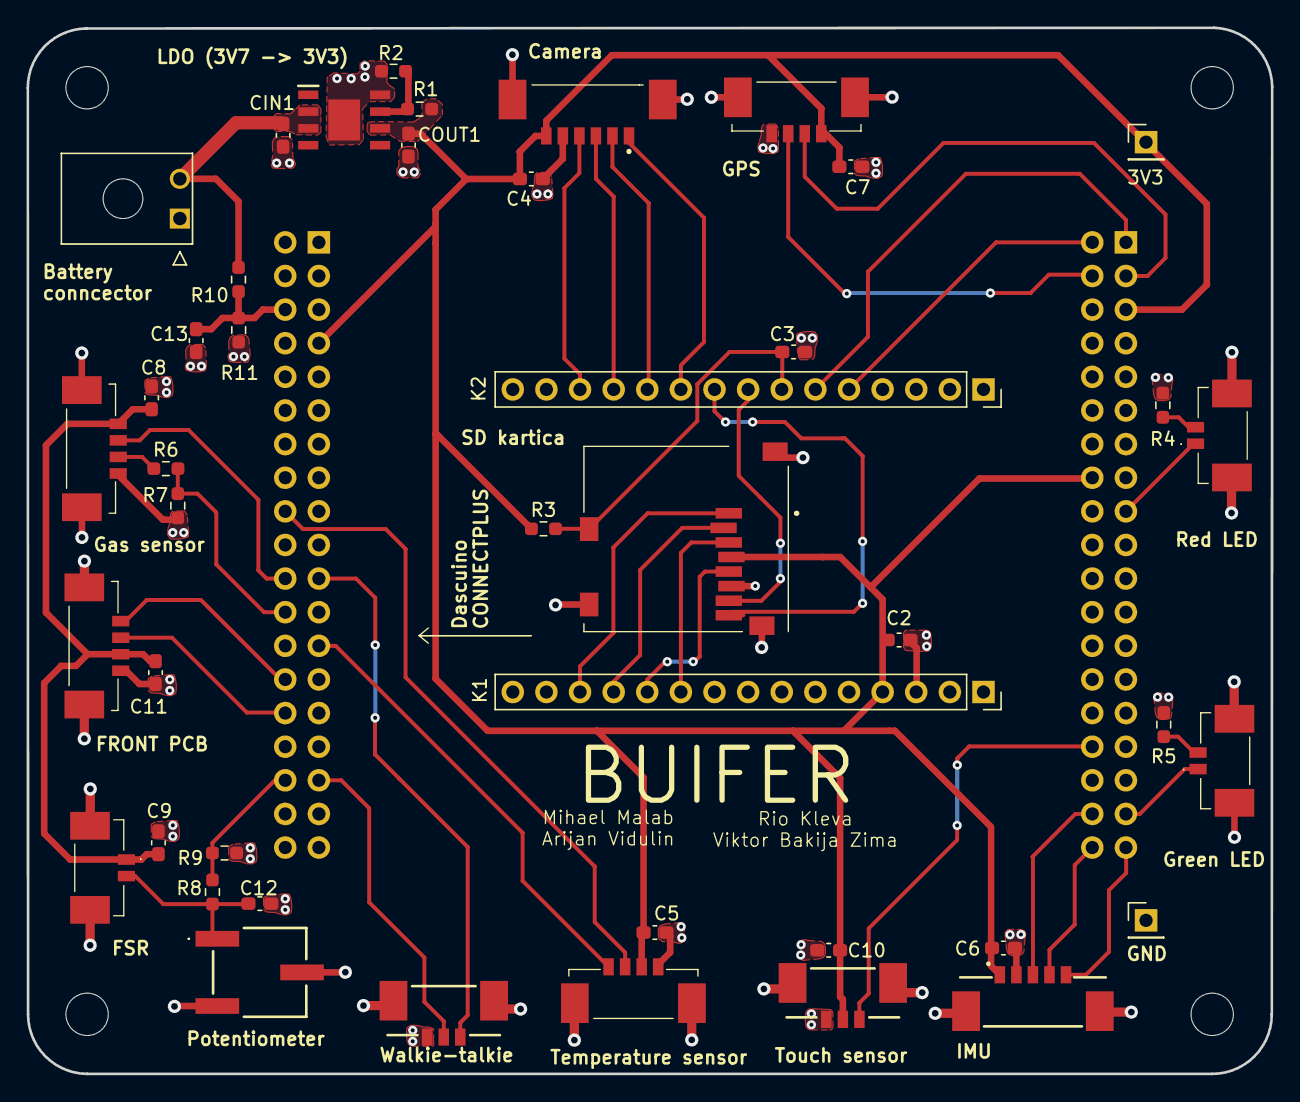
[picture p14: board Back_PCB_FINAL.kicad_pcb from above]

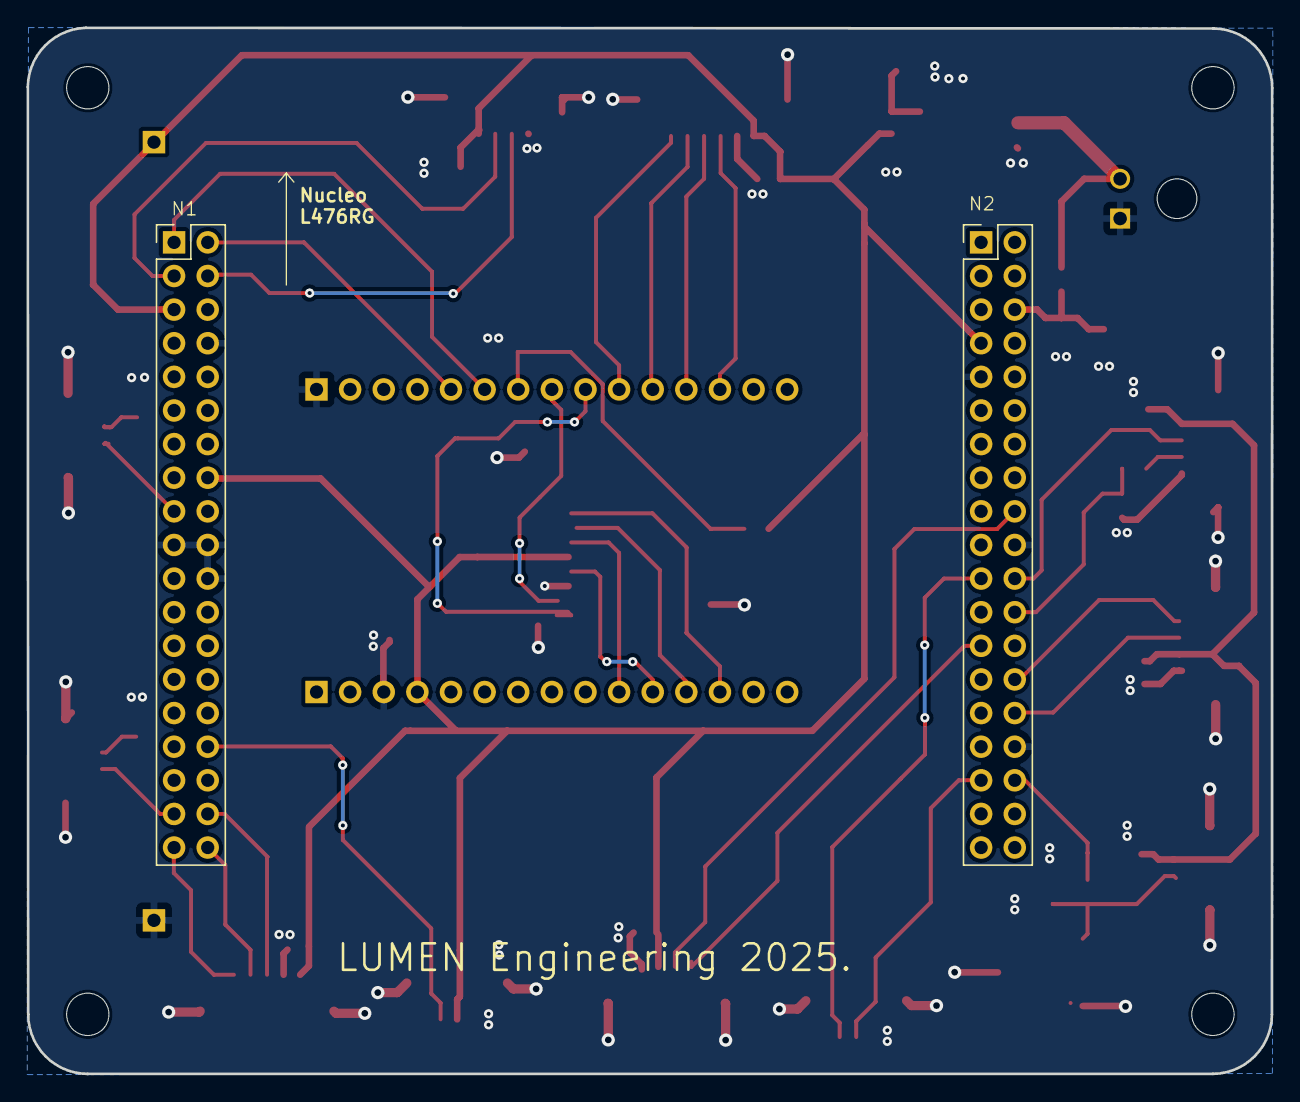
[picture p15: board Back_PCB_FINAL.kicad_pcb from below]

Board: 2 copper layers, 94.0 x 79.0 mm, 50 parts (2 on the bottom side), 40 nets.

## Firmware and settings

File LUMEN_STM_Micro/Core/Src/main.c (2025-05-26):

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
/* Includes ------------------------------------------------------------------*/
#include "main.h"
#include "cmsis_os.h"

/* USER CODE BEGIN Includes */

//Sensor includes
#include "shtc3.h"
#include "mpu6050.h"
#include "usr_gnss_parser.h"
#include "MQ2inC.h"

//C includes
#include "string.h"
#include "stdbool.h"
//FreeRTOS includes
#include "FreeRTOS.h"
#include "task.h"
#include "timers.h"
#include "queue.h"
#include "semphr.h"
#include "event_groups.h"
/* USER CODE END Includes */

/* USER CODE BEGIN PD */
#define G_CONSTANT 9.81f
/* USER CODE END PD */

ADC_HandleTypeDef hadc1;
ADC_HandleTypeDef hadc2;

I2C_HandleTypeDef hi2c2;
I2C_HandleTypeDef hi2c3;

TIM_HandleTypeDef htim1;
TIM_HandleTypeDef htim3;

UART_HandleTypeDef huart5;
UART_HandleTypeDef huart1;
UART_HandleTypeDef huart2;
UART_HandleTypeDef huart3;
DMA_HandleTypeDef hdma_uart5_rx;


/* USER CODE BEGIN PV */
static int32_t temp;
static int32_t hum;
static int flag = 0;
static int state = 0;
typedef struct {

	int32_t temperature;
	int32_t humidity;
	float latitude;
    float longitude;
	float altitude;
	float time;
	double accelX;
	double accelY;
	double accelZ;
	float lpg;
	float smoke;
	float co;
	float batStatus;

}data;

static data sendData;
static data measuredData;
static float duty_cycle = 0.0;
static uint32_t cmp_reg;
static UBaseType_t watermark;
static MPU6050_t imuData;
static float calValue = 0.902;
static S_GPS_L86_DATA gpsData;
static bool sameValueLow = false;
static bool sameValueMedium = false;
static bool sameValueHigh = false;
static bool helmetOnFlag = false;
static bool helmetOffFlag = false;
static bool highTemp = false;
static bool lowTemp = false;
//static float batMaxVoltage = 4.2;
static float voltageThresholdMaximum = 3.78;
static float voltageThresholdMinimum = 3.37;

static float acc_threshold = 20*G_CONSTANT;
static float accx;
static unsigned long lastSendTime;
static unsigned long sendInterval = 30000;
static float accel;
static int FSR_reading;
/* USER CODE END PV */

void SystemClock_Config(void);
void PeriphCommonClock_Config(void);
static void MX_GPIO_Init(void);
static void MX_DMA_Init(void);
static void MX_USART2_UART_Init(void);
static void MX_I2C2_Init(void);
static void MX_ADC1_Init(void);
static void MX_I2C3_Init(void);
static void MX_UART5_Init(void);
static void MX_USART3_UART_Init(void);
static void MX_TIM1_Init(void);
static void MX_USART1_UART_Init(void);
static void MX_ADC2_Init(void);
static void MX_TIM3_Init(void);


/* USER CODE BEGIN 0 */

/* ------ TASK HANDLES ------ */

xTaskHandle Measurements_Handler;
xTaskHandle Sender_Handler;
xTaskHandle LED_Handler;


/* ------ QUEUE HANDLES ------ */

xQueueHandle Queue_Handler;

/* ------ SEMAPHORE HANDLES ------ */

xSemaphoreHandle PWM_Sem_Handler;



/* ------ TASK FUNCTIONS ------ */

void measurements_task(void *pvParameters);
void sender_task(void *pvParameters);
void LED_task(void *pvParameters);
float square(float number);

/* USER CODE END 0 */

/**
  * @brief  The application entry point.
  * @retval int
  */
int main(void)
{
  /* MCU Configuration--------------------------------------------------------*/

  /* Reset of all peripherals, Initializes the Flash interface and the Systick. */
  HAL_Init();

  /* Configure the system clock */
  SystemClock_Config();

/* Configure the peripherals common clocks */
  PeriphCommonClock_Config();

  /* Initialize all configured peripherals */
  MX_GPIO_Init();
  MX_DMA_Init();
  MX_USART2_UART_Init();
  MX_I2C2_Init();
  MX_ADC1_Init();
  MX_I2C3_Init();
  MX_UART5_Init();
  MX_USART3_UART_Init();
  MX_TIM1_Init();
  MX_USART1_UART_Init();
  MX_ADC2_Init();
  MX_TIM3_Init();
  /* USER CODE BEGIN 2 */

  //HAL_GPIO_WritePin(GPIOA, GPIO_PIN_12, GPIO_PIN_SET);
  HAL_GPIO_WritePin(GPIOB,GPIO_PIN_14,GPIO_PIN_SET);
  MPU6050_Init(&hi2c3);
  UsrGpsL86Init(&huart5);
  begin(&hadc1);
  char buffer[100] = "80\n";
  HAL_Delay(500);
  HAL_UART_Transmit(&huart1,(uint8_t*)buffer,strlen(buffer), 50);
  HAL_Delay(5000);
  //HAL_UART_Transmit(&huart1,(uint8_t*)buffer,strlen(buffer), 50);
  /* ------ QUEUE RELATED ------ */
  Queue_Handler = xQueueCreate(2,sizeof(data));
  if (Queue_Handler == NULL) {

      Error_Handler();
  }

  /* ------ TASK RELATED ------ */
  xTaskCreate(measurements_task, "measure", 1024, NULL, 3, &Measurements_Handler);
  xTaskCreate(sender_task, "send data", 1024, NULL, 2, &Sender_Handler);
  xTaskCreate(LED_task, "toggle LED", 128, NULL, 1, &LED_Handler);


  /* ------ SEMAPHORE/MUTEX RELATED ------ */
  PWM_Sem_Handler = xSemaphoreCreateBinary();
  if (PWM_Sem_Handler == NULL) {

        Error_Handler();
    }

  vTaskStartScheduler();
  /* USER CODE END 2 */


  /* We should never get here as control is now taken by the scheduler */
  /* Infinite loop */
  /* USER CODE BEGIN WHILE */
  while (1)
  {
    /* USER CODE END WHILE */

    /* USER CODE BEGIN 3 */

  }
  /* USER CODE END 3 */
}

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
/* USER CODE BEGIN 4 */
	void measurements_task(void *pvParameters){
		while(1)
		{
			ADC_ChannelConfTypeDef sConfig;
			shtc3_perform_measurements(&hi2c2, &temp, &hum);

			MPU6050_Read_All(&hi2c3, &imuData);

			Usr_GpsL86GetValues(&gpsData);
			begin(&hadc1);
			measuredData.lpg = readLPG(&hadc1);
			measuredData.smoke = readSmoke(&hadc1);
			measuredData.co = readCO(&hadc1);
			HAL_ADC_Stop(&hadc1);
			sConfig.Channel = ADC_CHANNEL_13;
  	  	  	sConfig.Rank = ADC_REGULAR_RANK_1;
  	  	  	sConfig.SamplingTime = ADC_SAMPLETIME_2CYCLES_5;
  	  	  	sConfig.SingleDiff = ADC_SINGLE_ENDED;
  	  	  	sConfig.OffsetNumber = ADC_OFFSET_NONE;
  	  	  	sConfig.Offset = 0;

			if (HAL_ADC_ConfigChannel(&hadc1, &sConfig) != HAL_OK)
				{
				 Error_Handler();
				}
			HAL_ADC_Start(&hadc1); // start the adc

			HAL_ADC_PollForConversion(&hadc1, 100); // poll for conversion

			FSR_reading= HAL_ADC_GetValue(&hadc1); // get the adc value

			HAL_ADC_Stop(&hadc1); // stop adc*/

			measuredData.humidity = hum;
			measuredData.temperature = temp;
			measuredData.accelX = imuData.Ax;
			measuredData.accelY = imuData.Ay;
			measuredData.accelZ = imuData.Az;
			measuredData.latitude = gpsData.lat;
			measuredData.longitude = gpsData.lon;
			measuredData.altitude = gpsData.altitudeInMeter;
			//float gpsTimeSnapshot = gpsData.fixedTime;
			//measuredData.time = gpsTimeSnapshot;
			measuredData.time = gpsData.fixedTime;
			accx = measuredData.accelZ;

			HAL_ADC_Start(&hadc2);
			HAL_ADC_PollForConversion(&hadc2, 100);
			measuredData.batStatus = (HAL_ADC_GetValue(&hadc2)*4.2*calValue)/4095;
			HAL_ADC_Stop(&hadc2);

			accel = sqrt(square(imuData.Ax) + square(imuData.Ay) + square(imuData.Az));
			if (accel >= 2.0 ){
				char buffer[100];
				sprintf(buffer, "11\n");
				HAL_UART_Transmit(&huart3,(uint8_t*)buffer, strlen(buffer), 50);
			}

			if (measuredData.batStatus <= voltageThresholdMinimum && !sameValueLow){
				char buffer[100];
				sprintf(buffer,"10\n");
				HAL_UART_Transmit(&huart1,(uint8_t*)buffer,strlen(buffer), 50);
				HAL_UART_Transmit(&huart3,(uint8_t*)buffer,strlen(buffer), 50);
				HAL_GPIO_WritePin(GPIOA, GPIO_PIN_15, GPIO_PIN_SET);
				HAL_GPIO_WritePin(GPIOC, GPIO_PIN_2, GPIO_PIN_RESET);
				sameValueLow = true;
				sameValueMedium = false;
				sameValueHigh = false;
			}

			if (measuredData.batStatus >= voltageThresholdMinimum && measuredData.batStatus <= voltageThresholdMaximum && !sameValueMedium){
				char buffer[100];
				sprintf(buffer,"20\n");
				//HAL_UART_Transmit(&huart1,(uint8_t*)buffer,strlen(buffer), 50);
				HAL_UART_Transmit(&huart3,(uint8_t*)buffer,strlen(buffer), 50);
				HAL_GPIO_WritePin(GPIOA, GPIO_PIN_15, GPIO_PIN_RESET);
				HAL_GPIO_WritePin(GPIOC, GPIO_PIN_2, GPIO_PIN_RESET);
				sameValueLow = false;
				sameValueMedium = true;
				sameValueHigh = false;
			}

			if (measuredData.batStatus >= voltageThresholdMaximum && !sameValueHigh){
				char buffer[100];
				sprintf(buffer,"30\n");
				HAL_UART_Transmit(&huart1,(uint8_t*)buffer,strlen(buffer), 50);
				HAL_UART_Transmit(&huart3,(uint8_t*)buffer,strlen(buffer), 50);
				HAL_GPIO_WritePin(GPIOC, GPIO_PIN_2, GPIO_PIN_SET);
				HAL_GPIO_WritePin(GPIOA, GPIO_PIN_15, GPIO_PIN_RESET);
				sameValueLow = false;
				sameValueMedium = false;
				sameValueHigh = true;
			}

			if (measuredData.temperature >= 3000 && !highTemp){
				char buffer[100];
				sprintf(buffer,"40\n");
				HAL_UART_Transmit(&huart3,(uint8_t*)buffer,strlen(buffer), 50);
				HAL_UART_Transmit(&huart1,(uint8_t*)buffer,strlen(buffer), 50);
				highTemp = true;
				lowTemp = false;
			}else if(measuredData.temperature <= 3000 && !lowTemp){
				char buffer[100];
				sprintf(buffer,"70\n");
				HAL_UART_Transmit(&huart3,(uint8_t*)buffer,strlen(buffer), 50);
				highTemp = false;
				lowTemp = true;
			}

			if (FSR_reading >= 700.0 && !helmetOnFlag){
				char buffer[100];
				sprintf(buffer, "50\n");
				HAL_UART_Transmit(&huart3, (uint8_t*)buffer,strlen(buffer), 50);
				helmetOnFlag = true;
				helmetOffFlag = false;
			}else if (FSR_reading <= 700.0 && !helmetOffFlag){
				char buffer[100];
				sprintf(buffer, "60\n");
				HAL_UART_Transmit(&huart3, (uint8_t*)buffer,strlen(buffer), 50);
				helmetOnFlag = false;
			    helmetOffFlag = true;
			}

			unsigned long currentTime =  xTaskGetTickCount();

			if( currentTime - lastSendTime >= sendInterval){
			if(xQueueSend(Queue_Handler,&measuredData,portMAX_DELAY) == pdPASS){
				flag = 1;
			}
			lastSendTime = currentTime;
			}
			watermark = uxTaskGetStackHighWaterMark(NULL);
			vTaskDelay(pdMS_TO_TICKS(10));
		}
	}

	void sender_task(void *pvParameters){

		while(1){
			if(xQueueReceive(Queue_Handler, &sendData, portMAX_DELAY) == pdPASS){
				char buffer[100];
				sprintf(buffer,"%d %d %f %f %f %f %f %f\n", sendData.humidity, sendData.temperature,sendData.altitude,sendData.latitude,sendData.longitude,sendData.lpg,sendData.smoke,sendData.co);
				//xSemaphoreTake(AlarmMutex_Handler,portMAX_DELAY);
				HAL_UART_Transmit(&huart3,(uint8_t*)buffer, strlen(buffer), 50);
				//xSemaphoreGive(AlarmMutex_Handler);
			}
			//vTaskDelay(pdMS_TO_TICKS(0.5));
		}
	}


	void LED_task(void *pvParameters){

		while(1){
			if(xSemaphoreTake(PWM_Sem_Handler,portMAX_DELAY) == pdTRUE){

				if (state < 2){
							state++;
						}else state = 0;
					switch(state){
							  case 0:
								  cmp_reg = 0;
								  __HAL_TIM_SET_COMPARE(&htim3,TIM_CHANNEL_1,cmp_reg);
								  break;
							  case 1:
								  cmp_reg = 0.1 * htim3.Init.Period;
								  __HAL_TIM_SET_COMPARE(&htim3,TIM_CHANNEL_1,cmp_reg);
								  break;
							  case 2:
								  cmp_reg = 0.25 * htim3.Init.Period;
								  __HAL_TIM_SET_COMPARE(&htim3,TIM_CHANNEL_1,cmp_reg);
								  break;
					}
		}
	}
	}

	void HAL_GPIO_EXTI_Callback(uint16_t GPIO_Pin){
		if(GPIO_Pin == GPIO_PIN_4){
		  BaseType_t task_woken = pdFALSE;
		  xSemaphoreGiveFromISR(PWM_Sem_Handler,&task_woken);

		  if(task_woken){
			  portYIELD_FROM_ISR(task_woken);

		  }
		}
	  }

	/* ------- HELPING FUNCTIONS ------- */
	float square(float number){
		return number*number;
	}

/* USER CODE END 4 */


/**
  * @brief  Period elapsed callback in non blocking mode
  * @note   This function is called  when TIM6 interrupt took place, inside
  * HAL_TIM_IRQHandler(). It makes a direct call to HAL_IncTick() to increment
  * a global variable "uwTick" used as application time base.
  * @param  htim : TIM handle
  * @retval None
  */
void HAL_TIM_PeriodElapsedCallback(TIM_HandleTypeDef *htim)
{
  if (htim->Instance == TIM6) {
    HAL_IncTick();
  }
}

/**
  * @brief  This function is executed in case of error occurrence.
  * @retval None
  */
void Error_Handler(void)
{
  /* USER CODE BEGIN Error_Handler_Debug */
  /* User can add his own implementation to report the HAL error return state */
  __disable_irq();
  while (1)
  {
  }
  /* USER CODE END Error_Handler_Debug */
}

#ifdef  USE_FULL_ASSERT
/**
  * @brief  Reports the name of the source file and the source line number
  *         where the assert_param error has occurred.
  * @param  file: pointer to the source file name
  * @param  line: assert_param error line source number
  * @retval None
  */
void assert_failed(uint8_t *file, uint32_t line)
{
  /* USER CODE BEGIN 6 */
  /* User can add his own implementation to report the file name and line number,
     ex: printf("Wrong parameters value: file %s on line %d\r\n", file, line) */
  /* USER CODE END 6 */
}
#endif /* USE_FULL_ASSERT */

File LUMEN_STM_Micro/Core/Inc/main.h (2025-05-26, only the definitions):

#define B1_Pin GPIO_PIN_13
#define B1_GPIO_Port GPIOC
#define B1_EXTI_IRQn EXTI15_10_IRQn
#define IMU_SCL_Pin GPIO_PIN_0
#define IMU_SCL_GPIO_Port GPIOC
#define IMU_SDA_Pin GPIO_PIN_1
#define IMU_SDA_GPIO_Port GPIOC
#define BAT_FULL_Pin GPIO_PIN_2
#define BAT_FULL_GPIO_Port GPIOC
#define USART_TX_Pin GPIO_PIN_2
#define USART_TX_GPIO_Port GPIOA
#define USART_RX_Pin GPIO_PIN_3
#define USART_RX_GPIO_Port GPIOA
#define LD2_Pin GPIO_PIN_5
#define LD2_GPIO_Port GPIOA
#define FSR_Pin GPIO_PIN_4
#define FSR_GPIO_Port GPIOC
#define BAT_SENSE_Pin GPIO_PIN_5
#define BAT_SENSE_GPIO_Port GPIOC
#define GAS_ADC_Pin GPIO_PIN_1
#define GAS_ADC_GPIO_Port GPIOB
#define GAS_D_Pin GPIO_PIN_2
#define GAS_D_GPIO_Port GPIOB
#define TEMP_SCL_Pin GPIO_PIN_10
#define TEMP_SCL_GPIO_Port GPIOB
#define TEMP_SDA_Pin GPIO_PIN_11
#define TEMP_SDA_GPIO_Port GPIOB
#define LED_PWM_Pin GPIO_PIN_13
#define LED_PWM_GPIO_Port GPIOB
#define BOOST_ENABLE_Pin GPIO_PIN_14
#define BOOST_ENABLE_GPIO_Port GPIOB
#define WK_RX_Pin GPIO_PIN_9
#define WK_RX_GPIO_Port GPIOA
#define WK_TX_Pin GPIO_PIN_10
#define WK_TX_GPIO_Port GPIOA
#define TMS_Pin GPIO_PIN_13
#define TMS_GPIO_Port GPIOA
#define TCK_Pin GPIO_PIN_14
#define TCK_GPIO_Port GPIOA
#define BAT_LOW_Pin GPIO_PIN_15
#define BAT_LOW_GPIO_Port GPIOA
#define NET_ESP_RX_Pin GPIO_PIN_10
#define NET_ESP_RX_GPIO_Port GPIOC
#define NET_ESP_TX_Pin GPIO_PIN_11
#define NET_ESP_TX_GPIO_Port GPIOC
#define GPS_RX_Pin GPIO_PIN_12
#define GPS_RX_GPIO_Port GPIOC
#define GPS_TX_Pin GPIO_PIN_2
#define GPS_TX_GPIO_Port GPIOD
#define SWO_Pin GPIO_PIN_3
#define SWO_GPIO_Port GPIOB

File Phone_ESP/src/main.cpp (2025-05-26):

#include <Arduino.h>
#include "Application.h"
#include "esp_system.h"
#include "SampleSource.h"
#include "I2SOutputWAV.h"
#include "WAVFileReader.h"
//Define pins for Serial 2 UART
#define SERIAL2_RX_PIN 25
#define SERIAL2_TX_PIN 33
#define SERIAL2_BAUD_RATE 9600
// i2s pins WAV pins
i2s_pin_config_t i2s_wav_pins = {
    .bck_io_num = GPIO_NUM_18,
    .ws_io_num = GPIO_NUM_19,
    .data_out_num = GPIO_NUM_5,
    .data_in_num = -1};

// our application
Application *application;
//Added a semaphore to control the access to the serial port
SemaphoreHandle_t xSemaphoreMain = NULL; // Create semaphore handle
SampleSource *wav_sample_battery_low;
SampleSource *wav_sample_power_on;
SampleSource *wav_sample_toxic_gas;
SampleSource *wav_sample_high_temeperature;

I2SOutputWAV *wav_output_battery_low;
I2SOutputWAV *wav_output_power_on;
I2SOutputWAV *wav_output_toxic_gas;
I2SOutputWAV *wav_output_high_temeperature;


File m_file;
QueueHandle_t counterQueue = NULL;
QueueHandle_t passQueue = NULL;
QueueHandle_t soundQueue = NULL;
void setup()
{
  // put your setup code here, to run once:
  Serial.begin(115200);
    //Adeed pointers
  Serial.println("Starting up");

  SPIFFS.begin();

  Serial.println("Created sample source");
  wav_sample_battery_low = new WAVFileReader("/battery_low.wav");
  wav_sample_power_on = new WAVFileReader("/power_on.wav");
  wav_sample_toxic_gas = new WAVFileReader("/toxic_gas.wav");
  wav_sample_high_temeperature = new WAVFileReader("/high_temperature.wav");



  wav_output_battery_low = new I2SOutputWAV();
  wav_output_power_on = new I2SOutputWAV();
  wav_output_toxic_gas = new I2SOutputWAV();
  wav_output_high_temeperature = new I2SOutputWAV();
  
  delay(1000);
  int coreCount = ESP.getChipCores();
  Serial.print("Number of cores: ");
  Serial.println(coreCount);

  Serial2.begin(SERIAL2_BAUD_RATE, SERIAL_8N1, SERIAL2_RX_PIN, SERIAL2_TX_PIN);
  // xSemaphoreMain = xSemaphoreCreateBinary(); // Create a mutex semaphore
  //   if (xSemaphoreMain == NULL) {
  //   Serial.println("Failed to create semaphore");
  // } else {
  //   Serial.println("Semaphore created successfully");
  // }
  // xSemaphoreGive(xSemaphoreMain); // Give the semaphore to start with
  //xTaskCreatePinnedToCore()
  // start up the application
  //Create a queue to hold the counter value
  counterQueue = xQueueCreate(10, sizeof(int));
  passQueue = xQueueCreate(10, sizeof(int));
  soundQueue = xQueueCreate(10, sizeof(int));
  if (counterQueue == NULL) {
    Serial.println("Failed to create queue");
  } else {
    Serial.println("Queue created successfully");
  }
  application = new Application();
  application->begin();
  Serial.println("Application started");
}

void loop()
{

  // Serial.print("Running on core: ");
  // Serial.println(xPortGetCoreID());
  // nothing to do - the application is doing all the work

    static int counter = 0;
    static int pass = 0;
    if (Serial2.available()) {
          
      String input = Serial2.readStringUntil('\n');
      input.trim(); // Remove any trailing whitespace or newline characters
      Serial.print("From PuTTY: ");
      Serial.println(input);
      Serial2.print("Echo: ");
      Serial2.println(input);

      if (input == "20") {
        counter++;
        static int battery_low = 1;
          xQueueSend(counterQueue, &counter, 5);
          xQueueSend(soundQueue, &battery_low, 5);
              wav_output_battery_low->start(I2S_NUM_1, i2s_wav_pins, wav_sample_battery_low);
      
       
       } else if (input == "40") {
        counter++;
        static int power_on = 2;
              xQueueSend(counterQueue, &counter, 5);
              xQueueSend(soundQueue, &power_on, 5);
              wav_output_power_on->start(I2S_NUM_1, i2s_wav_pins, wav_sample_power_on);

       }
       else if (input == "50") {
        counter++;
        static int toxic_gas = 3;
              xQueueSend(counterQueue, &counter, 5);
              xQueueSend(soundQueue, &toxic_gas, 5);
              wav_output_toxic_gas->start(I2S_NUM_1, i2s_wav_pins, wav_sample_toxic_gas);
       }

       else if (input == "60") {
        counter++;
        static int high_temperature = 4;
            xQueueSend(counterQueue, &counter, 5);
            xQueueSend(soundQueue, &high_temperature, 5);
              wav_output_high_temeperature->start(I2S_NUM_1, i2s_wav_pins, wav_sample_high_temeperature);
       }
      
      
    }

  

  vTaskDelay(pdMS_TO_TICKS(1000));
  //Check if this thread is executing (it is)
  //Serial.println("Im here MF");
}

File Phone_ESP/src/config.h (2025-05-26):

#include <freertos/FreeRTOS.h>
#include <driver/i2s.h>
#include <driver/gpio.h>

// WiFi credentials
#define WIFI_SSID << YOUR_SSID >>
#define WIFI_PSWD << YOUR_PASSWORD >>

// sample rate for the system
#define SAMPLE_RATE 16000

// are you using an I2S microphone - comment this if you want to use an analog mic and ADC input
 #define USE_I2S_MIC_INPUT

// I2S Microphone Settings

// Which channel is the I2S microphone on? I2S_CHANNEL_FMT_ONLY_LEFT or I2S_CHANNEL_FMT_ONLY_RIGHT
// Generally they will default to LEFT - but you may need to attach the L/R pin to GND
#define I2S_MIC_CHANNEL I2S_CHANNEL_FMT_ONLY_LEFT
// #define I2S_MIC_CHANNEL I2S_CHANNEL_FMT_ONLY_RIGHT
#define I2S_MIC_SERIAL_CLOCK GPIO_NUM_18
#define I2S_MIC_LEFT_RIGHT_CLOCK GPIO_NUM_19
#define I2S_MIC_SERIAL_DATA GPIO_NUM_23

// Analog Microphone Settings - ADC1_CHANNEL_7 is GPIO35
#define ADC_MIC_CHANNEL ADC1_CHANNEL_7

// speaker settings
#define USE_I2S_SPEAKER_OUTPUT
#define I2S_SPEAKER_SERIAL_CLOCK GPIO_NUM_18
#define I2S_SPEAKER_LEFT_RIGHT_CLOCK GPIO_NUM_19
#define I2S_SPEAKER_SERIAL_DATA GPIO_NUM_5
// Shutdown line if you have this wired up or -1 if you don't
#define I2S_SPEAKER_SD_PIN I2S_PIN_NO_CHANGE

// transmit button
#define GPIO_TRANSMIT_BUTTON 2

// Which LED pin do you want to use? TinyPico LED or the builtin LED of a generic ESP32 board?
// Comment out this line to use the builtin LED of a generic ESP32 board
// #define USE_LED_GENERIC

// Which transport do you want to use? ESP_NOW or UDP?
// comment out this line to use UDP
 #define USE_ESP_NOW

// On which wifi channel (1-11) should ESP-Now transmit? The default ESP-Now channel on ESP32 is channel 1
#define ESP_NOW_WIFI_CHANNEL 1

// In case all transport packets need a header (to avoid interference with other applications or walkie talkie sets), 
// specify TRANSPORT_HEADER_SIZE (the length in bytes of the header) in the next line, and define the transport header in config.cpp
#define TRANSPORT_HEADER_SIZE 0
extern uint8_t transport_header[TRANSPORT_HEADER_SIZE];




// i2s config for using the internal ADC
extern i2s_config_t i2s_adc_config;
// i2s config for reading from of I2S
extern i2s_config_t i2s_mic_Config;
// i2s microphone pins
extern i2s_pin_config_t i2s_mic_pins;
// i2s speaker pins
extern i2s_pin_config_t i2s_speaker_pins;

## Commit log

2025-03-10 Temperature test 1
    Added file temp_test.txt
2025-05-10 Added connection with UART
2025-05-11 Working voice on demand, needs a bug fix
    [partitions.csv]
2025-05-14 Added humidity and temperature acquiring and sending functionality
2025-05-15 Added a prototype task for camera and interrupt to trigger camera
2025-05-16 Dynamic update of temperature graph with data from Firebase
2025-05-16 Improvements made , loop error still exists
    [Application.cpp, main.cpp]
2025-05-16 Null buffering added for edge case
2025-05-17 Camera and Status tabs added, notifications animations added
2025-05-17 Added camera picture taking via button
2025-05-22 Added the rest of the files, but only battery low still works
    [partitions.csv]
2025-05-22 This does not work, just testing
    [partitions.csv]
2025-05-22 Fixed I WAS HERE ISSUE
    [main.cpp]
2025-05-23 Added clear info buttons and a lot other stuff, final version
2025-05-26 Added STM code to main
    [LUMEN_STM_Micro Debug.cfg]
2025-06-15 Change Final folder to Phone_ESP
    [partitions.csv]

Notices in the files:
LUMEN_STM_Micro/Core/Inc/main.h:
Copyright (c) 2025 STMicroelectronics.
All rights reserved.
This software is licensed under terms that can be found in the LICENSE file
